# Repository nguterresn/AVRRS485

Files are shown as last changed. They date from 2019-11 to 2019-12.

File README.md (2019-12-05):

# AVR RS485  

## Contents

- [System Concept](#System-Concept)
- [USART Configuration](#USART-Configuration)
- [Frame Format](#Frame-Format)
- [Transmission](#Transmission)
	- [Address Frame](#Address-Frame)
	- [Data Frame](#Data-Frame)
- [Reception](#Reception)
- [Setup](#Setup)
- [System Diagram](#System-Diagram)
	- [Multi-processor Communication Mode](#Multi-processor-Communication-Mode)
	- [LED Commands](#LED-Commands)
- [PCB](#PCB)
	- [Schematic](#Schematic)
	- [PCB Design](#PCB-Design)

### System Concept

Captura de ecrã 2019-11-13, às 16 04 25

### USART Configuration

### Initialization

Since the [PlatformIO](https://platformio.org) serial monitor is set to a baudrate of 9600, the USART baudrate should be 9600 in order to monitor data:

```
#define FOSC 16000000 
#define BAUD 9600
#define MYUBRR FOSC/16/BAUD-1
```
###### Note: Microcontroller frequency is set to 16 MHz.

To be able to use USART, the receiver (RX) and the transmitter (TX) should be enable:
```
UCSR0B = (1<<RXEN0)|(1<<TXEN0)|(1<<UCSZ02);
```

The frame format should have a **9th bit** to distinguish between address frames and data frames (+1 stop bits):
```
UCSR0C = (1<<UCSZ00)|(1<<UCSZ01);
```

### Frame Format

Frame | start | 0 | 1 | 2 | 3 | 4 | 5 | 6 | 7 | 8 | stopbit 
--- | --- | --- | --- |--- |--- |--- |--- |--- |--- |--- |--- 
Bit | LOW | X | X | X | X | X | X | X | X | X | HIGH 

### Transmission

#### Address Frame

To send an Address Frame:

```
send_addr(SLAVE1_ADDR);
```

Waits until the channel is empty, saves 1 into TXB8 (9 bit) and sends address:

```
...
while (!(UCSR0A & (1<<UDRE0)));

UCSR0B |= (1<<TXB80);

UDR0 = addr;
```

#### Data Frame

To send a Data Frame:

```
send_data(ON);
...
send_data(OFF);
```

Waits until the channel is empty, saves 0 into TXB8 (9 bit) and sends data:

```
...
while (!(UCSR0A & (1<<UDRE0)));

UCSR0B &= ~(1<<TXB80);

UDR0 = data;
```

### Reception

To receive, call:

```
get_data(&ADDRESS or &DATATYPE):
```

Waits for until receives something and checks if one of these error occur:

- Frame Error
- Data OverRun

```
...
while (!(UCSR0A & (1<<RXC0)));

if (UCSR0A & ((1<<FE0)|(1<<DOR0)))
	return ERROR;
```

###### Note: Frame Error happens when, i.e., the next character of stop bit is 0. 
###### Note: Data OverRun occurs when the receive buffer is full.
###### Note: USART Parity Error (UPE0) is not enable since there is no parity bit in the initialize frame.

After checking errors appearance, ninth bit is filtered from UCSR0B register and it is returned. The parameter buffer is updated with new received data from *UDR0*:

```
...
ninthbit = (ninthbit >> 1) & 0x01; 

*buffer = UDR0;

return ninthbit;
```

### Setup

LED and RS485 Enable Pin is setup as an Output. 

```
pinMode(LED_PIN, OUTPUT);
pinMode(WREN_PIN, OUTPUT);
```

To read the digital values of the DIP Switch, pull-up resistors are enable and node address is calculated:

```
pinMode(ADDR0_PIN, INPUT_PULLUP);
pinMode(ADDR1_PIN, INPUT_PULLUP);
pinMode(ADDR2_PIN, INPUT_PULLUP);
pinMode(ADDR3_PIN, INPUT_PULLUP);

ADDR = digitalRead(ADDR0_PIN) | digitalRead(ADDR1_PIN)<<1 | digitalRead(ADDR2_PIN)<<2 | digitalRead(ADDR3_PIN)<<3;
```

In case of master address, the pull-up resistors connected to the buttons are enable and the RS485 enable pin (WREN_PIN) is set to 1, in order to be able to send data to the slaves:

```
if (ADDR == MASTER_ADDR) {

	pinMode(BUT1_PIN, INPUT_PULLUP);
	pinMode(BUT2_PIN, INPUT_PULLUP);
	
	digitalWrite(WREN_PIN, HIGH);
	
} 
```

On the other hand, the Multi-processor Communication Mode is disable, the LED is turned off and the RS485 enable pin (WREN_PIN) is set to 0, in order to be able to receive data from the master:

```
/* SLAVE */
else
{
	/* Multi-processor Communication Mode */
	UCSR0A = (1<<MPCM0);
	
	digitalWrite(LED_PIN, LOW);
	
	digitalWrite(WREN_PIN, LOW);
}
```

### System Diagram
#### Master-Slave - Slave Side

blockdiagramMS-2

#### Multi-processor Communication Mode

This method allows to distinguish between address and datatype frames. When a node is considered addressed, the multi-processor communication mode is enable, it only receives datatype commands and discards address frames, until multi-processor communication mode is disable:

```
...
/* If address received from master matches the local address set by the DIP switches. */

/* ADDRESSED */
if (ADDR_R == ADDR) {
	
	/* Multi-processor Communication Mode ENABLE */
	UCSR0A &= 0xfe; 
	
	/* Received frames are all of datatype format, addressed ones are discarded */
	
	/* Multi-processor Communication Mode DISABLE */
	UCSR0A |= (1<<MPCM0); 

} 
```

#### LED Commands

The LED is turned on and turned off by received ON and OFF (from the master), respectively, with value 255 and 127.
This received value is shifted 7 bits to have a value between 0 and 1, in order to command the LED:

```
...
digitalWrite(LED_PIN, data>>7 & 0x01);
...
```

### PCB
This circuit was designed to be easily tested and programmed. In addition to the mandatory requirements, a FT232 interface, a AVR ISP and a 5V voltage regulator was added as optional requirements. 
- The FT232 interface will allow testing Rx and Tx communications using a [FTDI](https://en.wikipedia.org/wiki/FTDI) chip connected to a USB port, using a computer to track results. 
- The [ISP](https://www.elementzonline.com/image/cache/catalog/data/products/Programmers%20and%20Debuggers/USBasp/isp_header-500x500.jpg) interface will allow uC to be programmed.
- 5V Voltage regulator (7805) allows acceptance of higher input voltages (up to 12V) without compromising the system behavior. 

#### Schematic

sch

#### PCB Design

 - Trace's width: 0.3mm. Able to handle 1A through the circuit.

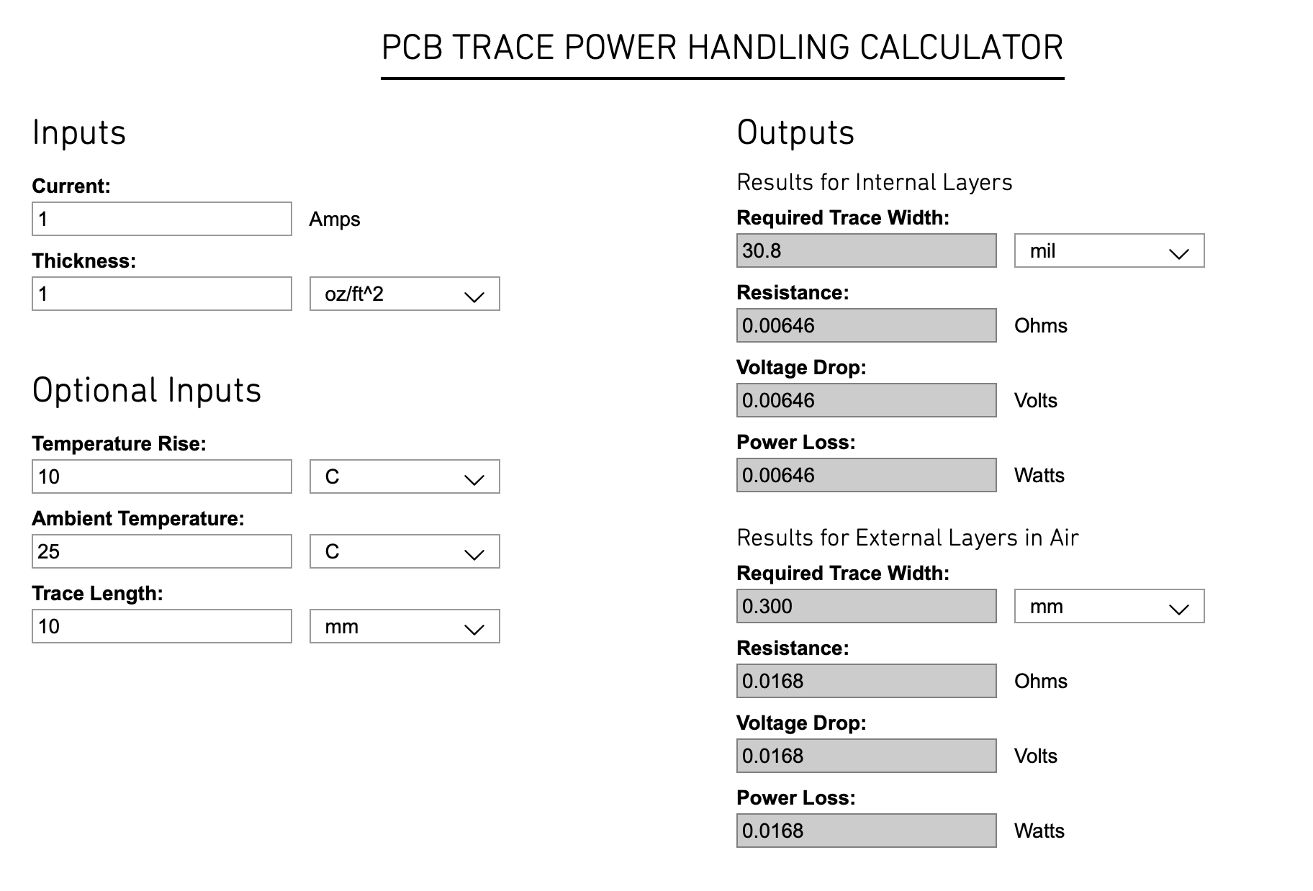
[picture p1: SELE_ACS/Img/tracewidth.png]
tracewidth


##### V0.1.1

designpcb

##### V0.1.2
- Crystal Capacitors (22pF) were changed to ceramic to match crystal performance requirements.
PCB

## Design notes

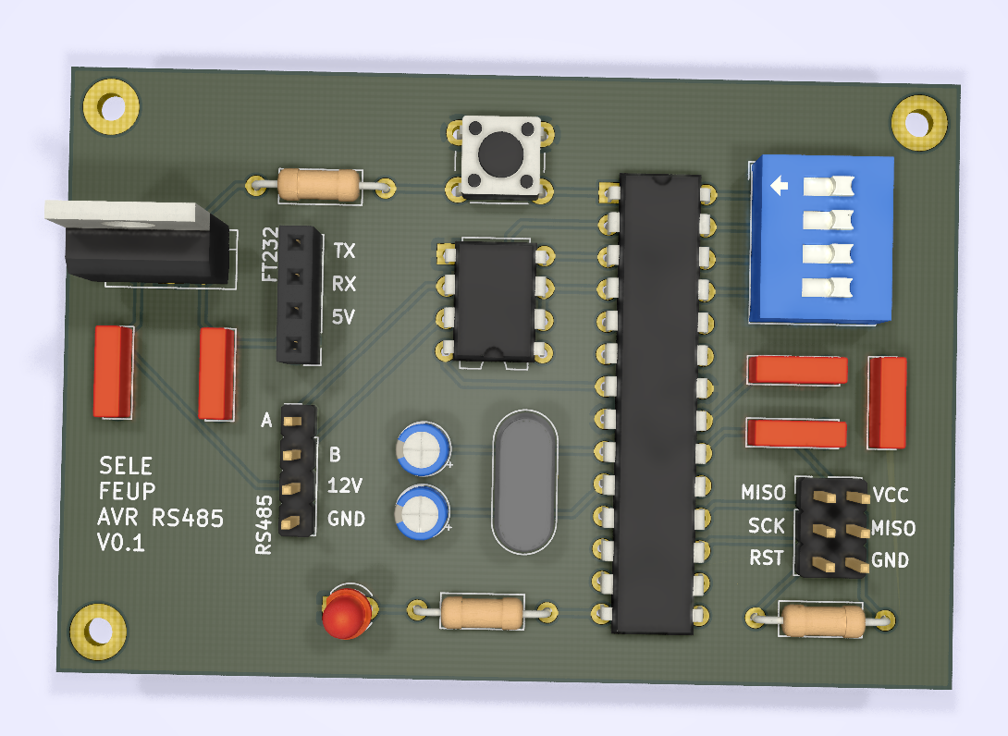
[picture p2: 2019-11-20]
SELE_ACS/Img/designpcb.png

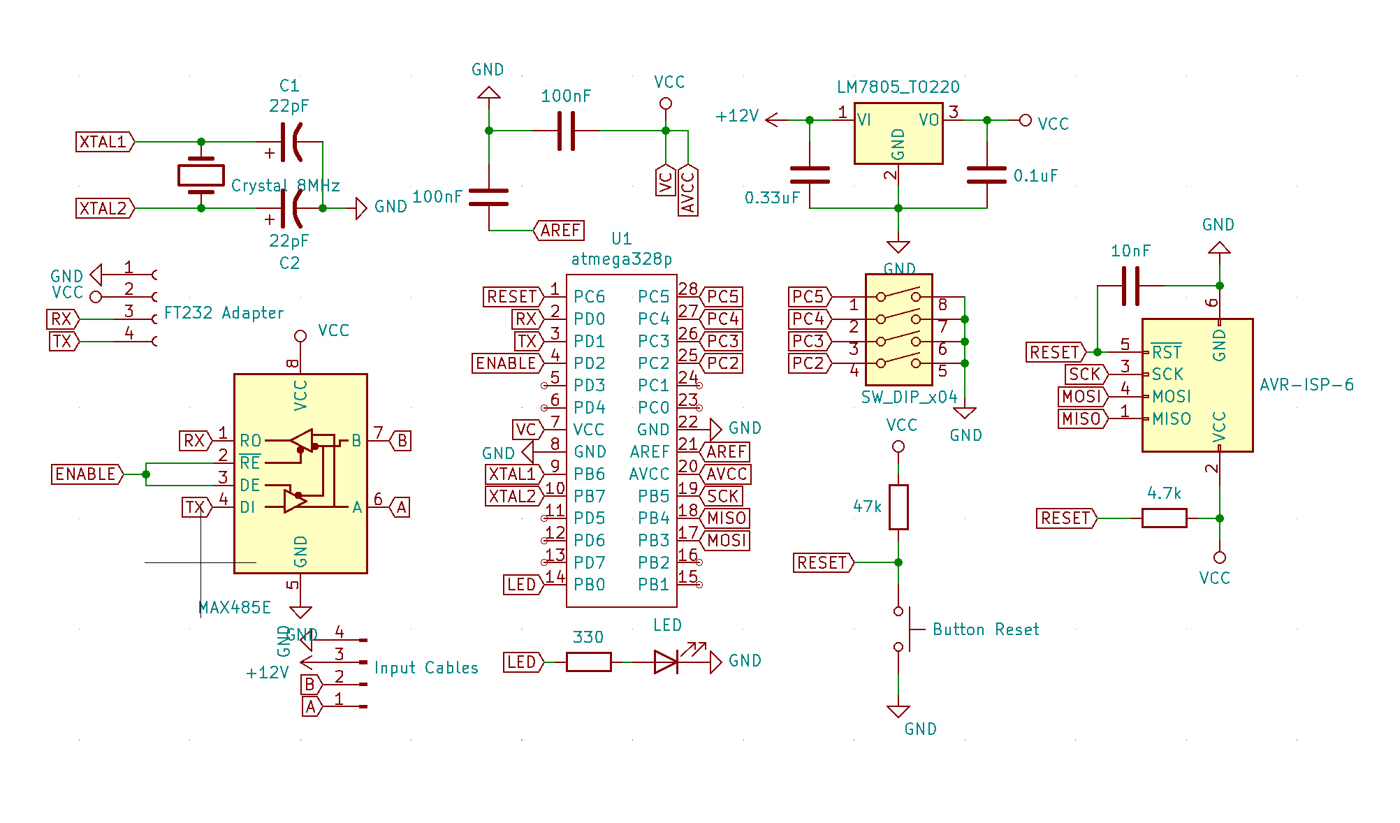
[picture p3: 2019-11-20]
SELE_ACS/Img/sch.png

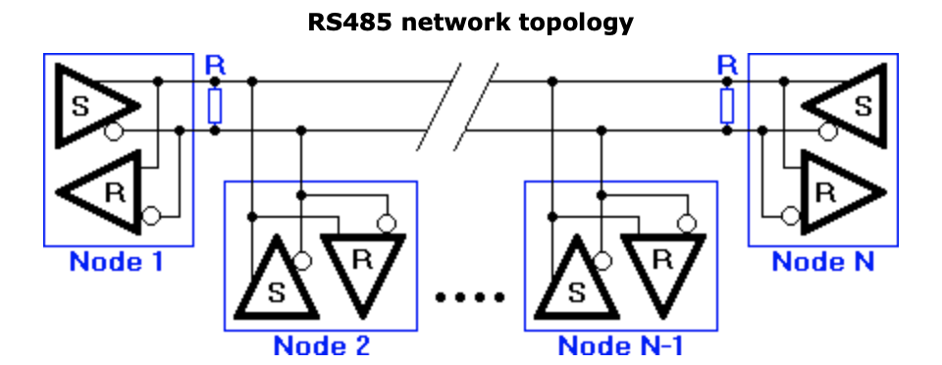
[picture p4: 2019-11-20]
SELE_ACS/Img/nodes.png

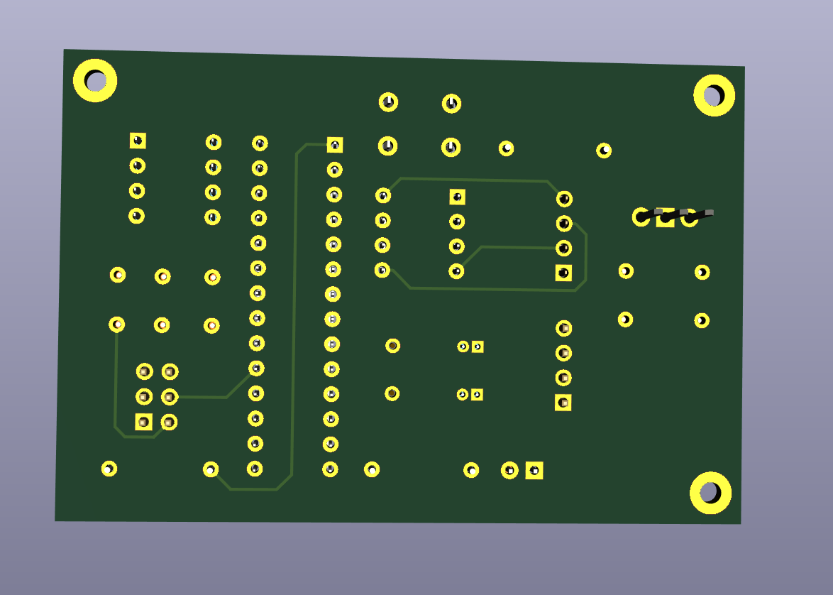
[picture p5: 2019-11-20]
SELE_ACS/Img/bCu.png

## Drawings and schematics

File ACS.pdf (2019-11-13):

# Asynchronous Communication System

# Master

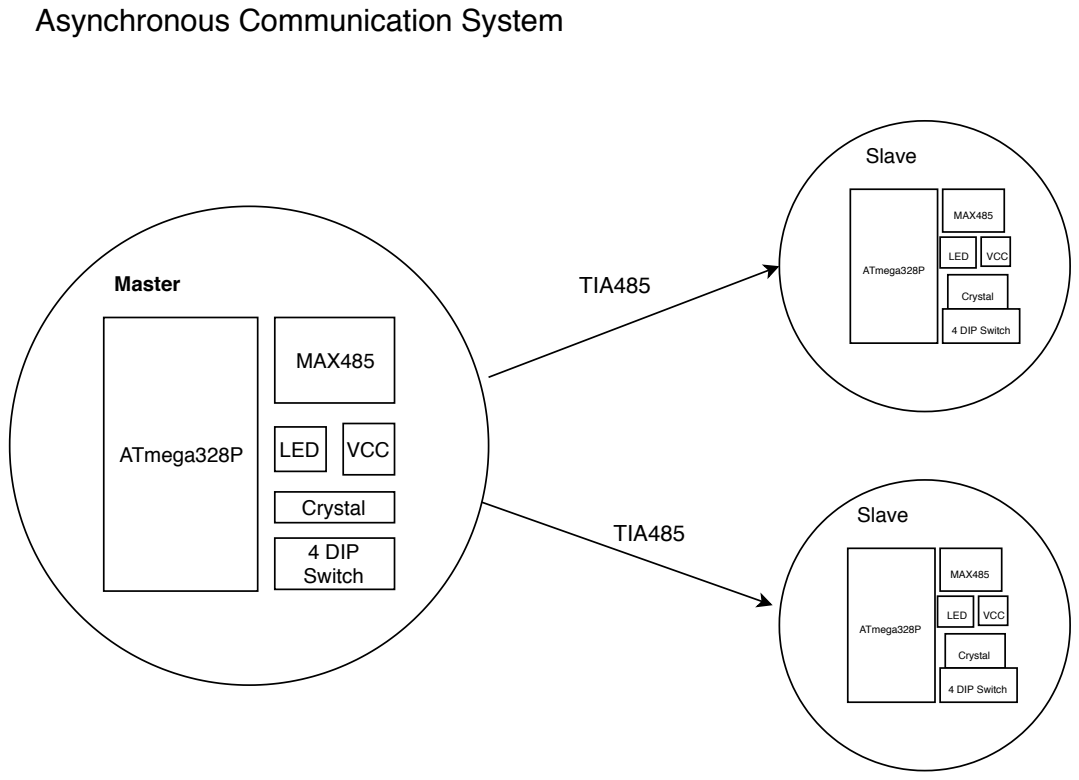
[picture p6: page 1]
Slave; TIA485; ATmega328P; MAX485; LED; Crystal; VCC; 4 DIP Switch

ATmega328P | MAX485

LED | VCC

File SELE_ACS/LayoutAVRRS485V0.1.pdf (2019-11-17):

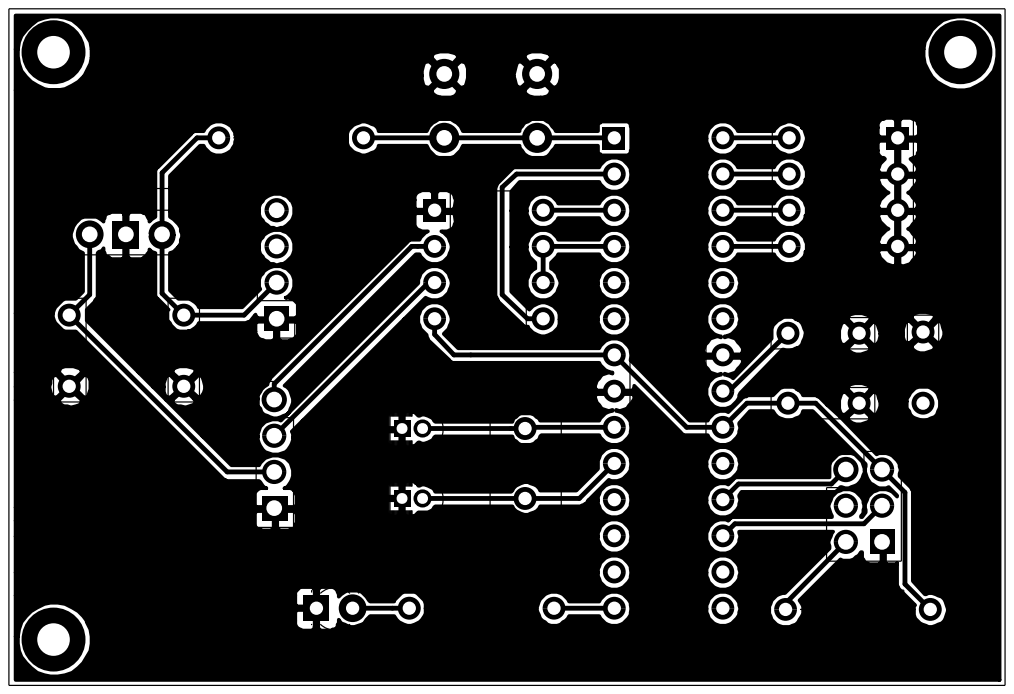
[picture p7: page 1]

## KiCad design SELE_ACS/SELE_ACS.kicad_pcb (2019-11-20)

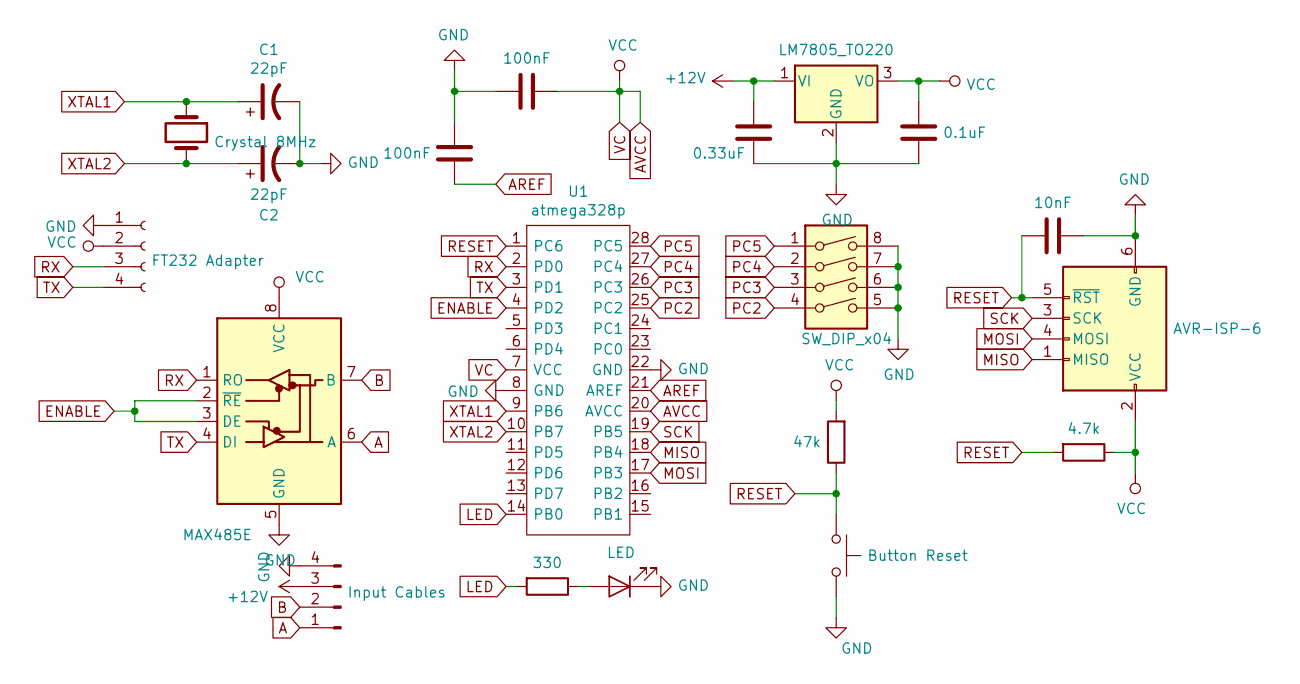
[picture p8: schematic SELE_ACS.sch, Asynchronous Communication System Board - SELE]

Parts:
C1, C2: 22pF; C_Rect_L7.0mm_W2.0mm_P5.00mm
C3, C4: 100nF; C_Rect_L7.0mm_W2.0mm_P5.00mm
C5: 10nF; C_Rect_L7.0mm_W2.0mm_P5.00mm
C6: 0.33uF; C_Rect_L7.0mm_W2.0mm_P5.00mm
C7: 0.1uF; C_Rect_L7.0mm_W2.0mm_P5.00mm
D1: LED; LED_D3.0mm
J1: AVR-ISP-6; PinHeader_2x03_P2.54mm_Vertical
J2: Input Cables; PinHeader_1x04_P2.54mm_Vertical
J3: FT232 Adapter; Socket_Strip_Straight_1x04_Pitch2.54mm
R1: 330; R_Axial_DIN0207_L6.3mm_D2.5mm_P10.16mm_Horizontal
R2: 4.7k; R_Axial_DIN0207_L6.3mm_D2.5mm_P10.16mm_Horizontal
R3: 47k; R_Axial_DIN0207_L6.3mm_D2.5mm_P10.16mm_Horizontal
SW1: Button Reset; SW_PUSH_6mm
SW2: SW_DIP_x04; SW_DIP_SPSTx04_Slide_9.78x12.34mm_W7.62mm_P2.54mm
U1: atmega328p; DIP-28_W7.62mm
U2: MAX485E; DIP-8_W7.62mm
U3: LM7805_TO220; TO-220-3_Vertical
Y1: Crystal 8MHz; Crystal_HC49-U_Vertical

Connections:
+12V: C6.1, J2.3, U3.1 (VI)
A: J2.1, U2.6 (A)
AREF: C3.1, U1.21 (AREF)
AVCC: C4.1, C7.1, J1.2 (VCC), J3.2, R2.1, R3.2, U1.7 (VCC), U1.20 (AVCC), U2.8 (VCC), U3.3 (VO)
B: J2.2, U2.7 (B)
ENABLE: U1.4 (PD2), U2.2 (~RE), U2.3 (DE)
GND: C1.2, C2.2, C3.2, C4.2, C5.1, C6.2, C7.2, D1.1 (K), J1.6 (GND), J2.4, J3.1, SW1.2, SW2.5, SW2.6, SW2.7, SW2.8, U1.8 (GND), U1.22 (GND), U2.5 (GND), U3.2 (GND)
LED: R1.2, U1.14 (PB0)
MISO: J1.1 (MISO), U1.18 (PB4)
MOSI: J1.4 (MOSI), U1.17 (PB3)
unnamed: D1.2 (A), R1.1
PC2: SW2.4, U1.25 (PC2)
PC3: SW2.3, U1.26 (PC3)
PC4: SW2.2, U1.27 (PC4)
PC5: SW2.1, U1.28 (PC5)
RESET: C5.2, J1.5 (~RST), R2.2, R3.1, SW1.1, U1.1 (PC6)
RX: J3.3, U1.2 (PD0), U2.1 (RO)
SCK: J1.3 (SCK), U1.19 (PB5)
TX: J3.4, U1.3 (PD1), U2.4 (DI)
XTAL1: C1.1, U1.9 (PB6), Y1.1
XTAL2: C2.1, U1.10 (PB7), Y1.2

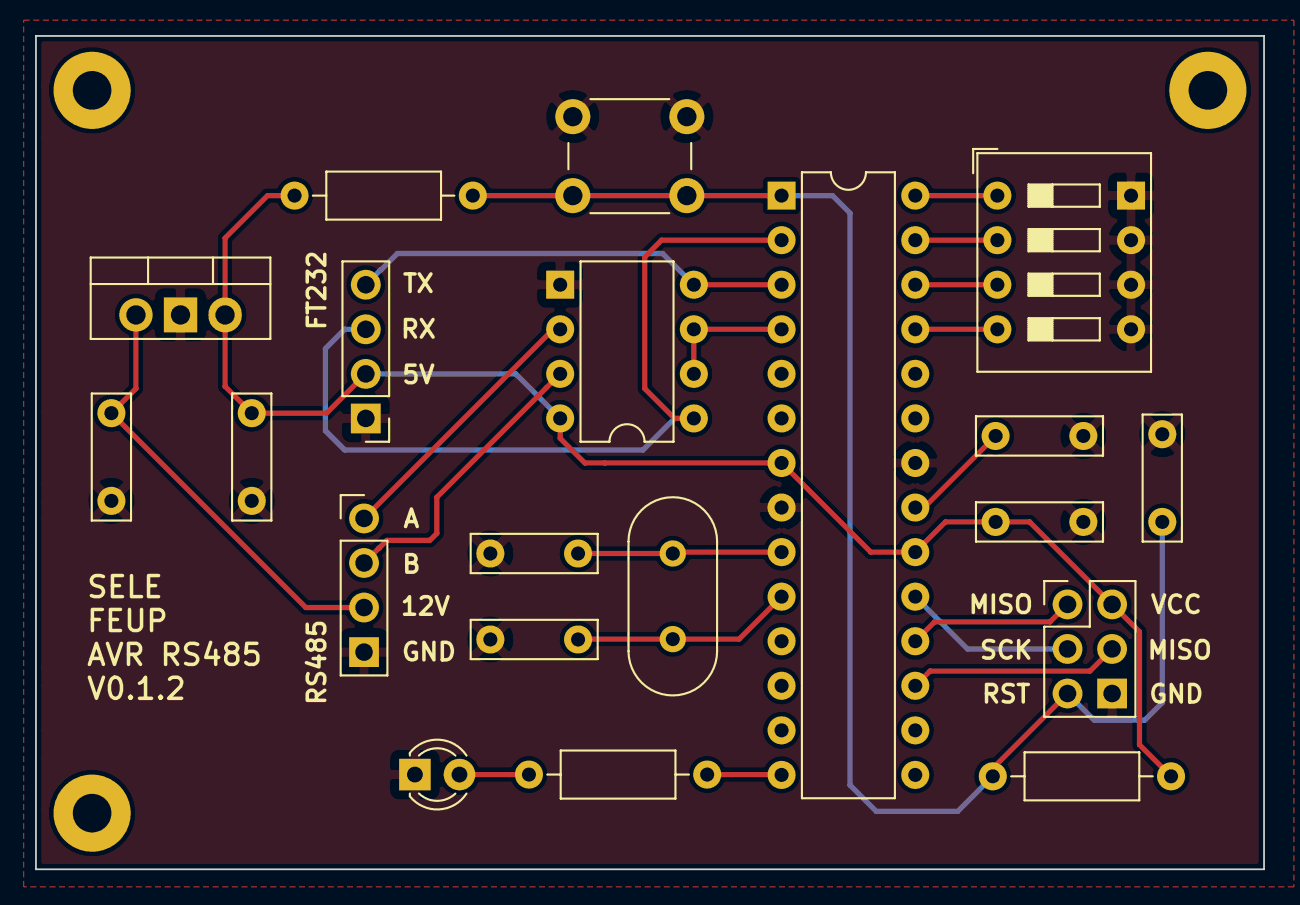
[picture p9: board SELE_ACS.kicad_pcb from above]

Board: 2 copper layers, 70.0 x 47.5 mm, 20 parts (0 on the bottom side), 21 nets.

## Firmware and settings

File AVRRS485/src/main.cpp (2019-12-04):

#include <Arduino.h>

#define MASTER_ADDR 15
#define SLAVE1_ADDR 13
#define SLAVE2_ADDR 14
#define ON 255  // b11111111
#define OFF 127 // b01111111
#define ERROR 43

uint8_t ADDR, ADDR_R;
uint8_t data;
uint8_t button1 = 0, button2 = 0;

#define LED_PIN   13
#define ADDR3_PIN 11
#define ADDR2_PIN 10
#define ADDR1_PIN 9
#define ADDR0_PIN 8
#define BUT1_PIN  7
#define BUT2_PIN  6
#define WREN_PIN  2

#define FOSC 16000000 // Clock Speed #define BAUD 9600
#define BAUD 9600
#define MYUBRR FOSC/16/BAUD-1

void send_data(uint8_t data);

void asynch9_init(long ubrr) {

    /*Set baud rate */
    UBRR0H = (unsigned char)(ubrr>>8); 
    UBRR0L = (unsigned char) ubrr;

    /* Enable receiver and transmitter */ 
    UCSR0B = (1<<RXEN0)|(1<<TXEN0)|(1<<UCSZ02);

    /* Set frame format: 9data, 1stop bit. No parity bit, AS USART */ 
    UCSR0C = (1<<UCSZ00)|(1<<UCSZ01);
}

void send_addr(uint8_t addr) {
  // put your code here, to send an address:
    while (!(UCSR0A & (1<<UDRE0)));
    /* Copy 9th bit to TXB8 */
    UCSR0B |= (1<<TXB80); // 1 means address
    /* Put data into buffer, sends the data */ 
    UDR0 = addr;
}

void send_data(uint8_t data) {
    
    // put your code here, to send a data byte:
    /* Wait for empty transmit buffer */
    while (!(UCSR0A & (1<<UDRE0)));
    /* Copy 9th bit to TXB8 */
    UCSR0B &= ~(1<<TXB80); // 0 means data
    /* Put data into buffer, sends the data */ 
    UDR0 = data;
}

uint8_t get_data(uint8_t *buffer) {
    
    // put your code here, to receive a data byte using multi processor communication mode:
	unsigned char status, ninthbit;

    /* Wait for data to be received */ 
    while (!(UCSR0A & (1<<RXC0)));

    /* Get status and 9th bit, then data */
    /* from buffer */ 
    status = UCSR0A; 
    ninthbit = UCSR0B; 

    /* If error, return -1 */
    if (status & ((1<<FE0)|(1<<DOR0)))
        return ERROR;// <- is signed

    /* Filter the 9th bit, then return */ 
    /* delimita o registo ao nono bit */
    ninthbit = (ninthbit >> 1) & 0x01; 

	*buffer = UDR0;

    return ninthbit;

}

void setup() {
  // put your setup code here, to run once:

  	asynch9_init(MYUBRR);
  	pinMode(LED_PIN, OUTPUT);
  	pinMode(WREN_PIN, OUTPUT);

  	pinMode(ADDR0_PIN, INPUT_PULLUP);
  	pinMode(ADDR1_PIN, INPUT_PULLUP);
  	pinMode(ADDR2_PIN, INPUT_PULLUP);
	pinMode(ADDR3_PIN, INPUT_PULLUP);

	digitalWrite(WREN_PIN, LOW);

  	ADDR = digitalRead(ADDR0_PIN) | digitalRead(ADDR1_PIN)<<1 | digitalRead(ADDR2_PIN)<<2 | digitalRead(ADDR3_PIN)<<3;

	if (ADDR == MASTER_ADDR) {
		pinMode(BUT1_PIN, INPUT_PULLUP);
		pinMode(BUT2_PIN, INPUT_PULLUP);
	} 
	else
	{
		/* Multi-processor Communication Mode */
		UCSR0A = (1<<MPCM0);
		digitalWrite(LED_PIN, LOW);
	}

}

void loop() {

	if (ADDR == MASTER_ADDR) {

		digitalWrite(WREN_PIN, HIGH);
		
		/* Pull up  */
		while (!(digitalRead(BUT1_PIN))) {

			if (!button1) {
				send_addr(SLAVE1_ADDR);
				send_data(ON);
				button1 = 1;
			}

		}

		while (!(digitalRead(BUT2_PIN))) {

			if (!button2) {
				send_addr(SLAVE2_ADDR);
				send_data(ON);
				button2 = 1;
				}

			}

		if (button1 || button2)
			send_data(OFF);

		button1 = 0;
		button2 = 0;

	} else {

		get_data(&ADDR_R);

		/* ADDRESSED */
		if (ADDR_R == ADDR) {

			UCSR0A &= 0xfe; 
			
			get_data(&data);
			digitalWrite(LED_PIN, data>>7 & 0x01);
			get_data(&data);
			digitalWrite(LED_PIN, data>>7 & 0x01);

			UCSR0A |= (1<<MPCM0); 

		} 
		
			
	}
}

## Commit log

2019-11-13 Sch done
    [SELE_ACS.kicad_pcb, SELE_ACS.sch]
2019-11-14 Add files via upload
    7805 e ft232 adapter
    [SELE_ACS.kicad_pcb, SELE_ACS.sch]
2019-11-16 Add files via upload
    pcbnew added
    socket symbol, footprint and 3d model added
    [SELE_ACS.sch]
2019-11-17 Add files via upload
    new pub
    [SELE_ACS.kicad_pcb, SELE_ACS.sch]
2019-11-17 Add files via upload
    gerber up
    [SELE_ACS-B_Cu.gbr, SELE_ACS-B_Mask.gbr, SELE_ACS-B_SilkS.gbr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]
2019-11-20 Add files via upload
    v0.1.2
    [SELE_ACS.kicad_pcb, SELE_ACS.sch]
